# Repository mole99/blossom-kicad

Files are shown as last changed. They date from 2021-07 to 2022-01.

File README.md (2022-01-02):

# Blossom

Blossom is my attempt at an Open Source Board designed using [KiCad 6](https://www.kicad.org/) and [OpenSCAD](https://openscad.org/). It packs 12 LEDs driven by a technique called Charlieplexing and 3 Buttons which are read using one analog pin. The board itself resembles a flower, at its heart an ATtiny85 MCU.

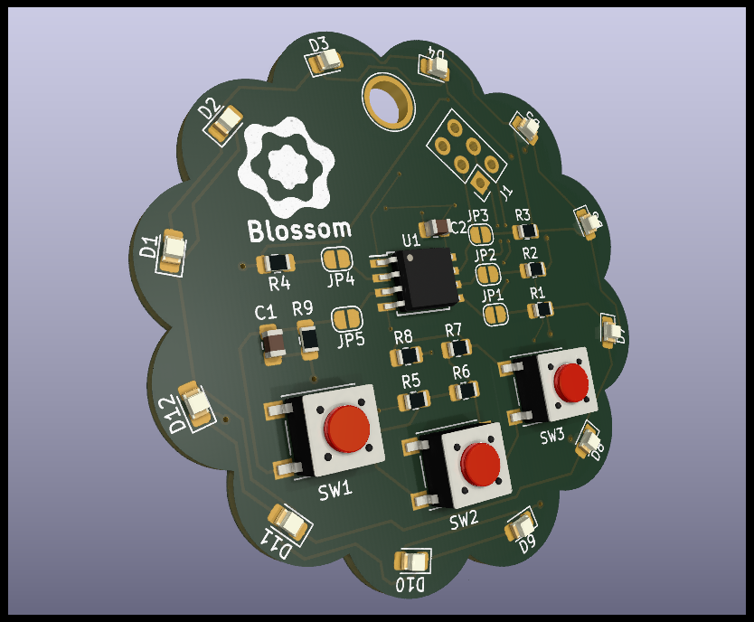
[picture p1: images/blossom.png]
3D-render


The firmware for the board can be found in the [blossom-firmware](https://github.com/mole99/blossom-firmware) repository.

Have a look at the interactive BOM [here](https://htmlpreview.github.io/?https://github.com/mole99/blossom-kicad/blob/main/ibom/ibom.html).

# The KiCad Project

The project related files are placed in `kicad/`. The aim of the project was to learn a lot and besides that create a small PCB controlled by an ATtiny85 which blinks some LEDs and reads in input from three buttons.

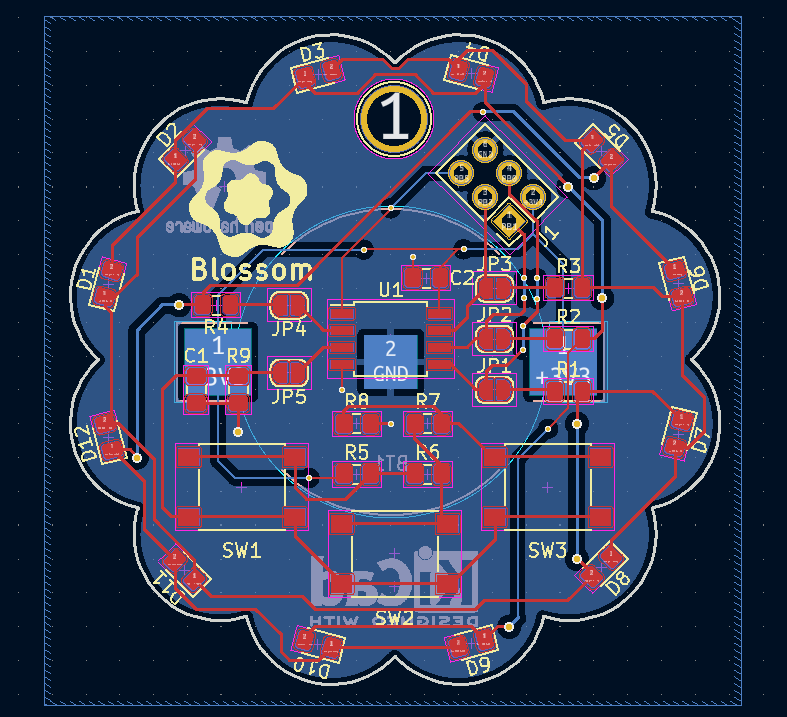
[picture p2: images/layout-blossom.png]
layout


The 12 LEDs are controlled by just 4 pins using [Charlieplexing](https://en.wikipedia.org/wiki/Charlieplexing). The current states of the 3 buttons is sampled by charging a capacitor depending on which button is pressed and reading the analog input.

# The board outline

You can find the files used to create the board outline and various positions for holes and the position of the LEDs under `cad/`.

To open the files you need to install [OpenSCAD](https://openscad.org/).

# Custom silkscreen icons

Using a tool called `svg2mod` I was able to convert a SVG icon drawn in Inkscape to a KiCad footprint module file. You can find the files in `icons/`.

You can easily do this with this command:

> svg2mod -i blossom.svg -o blossom.kicad_mod -p 0.1

where `p` stands for precision, the smaller the more precise.

# The finished PCB

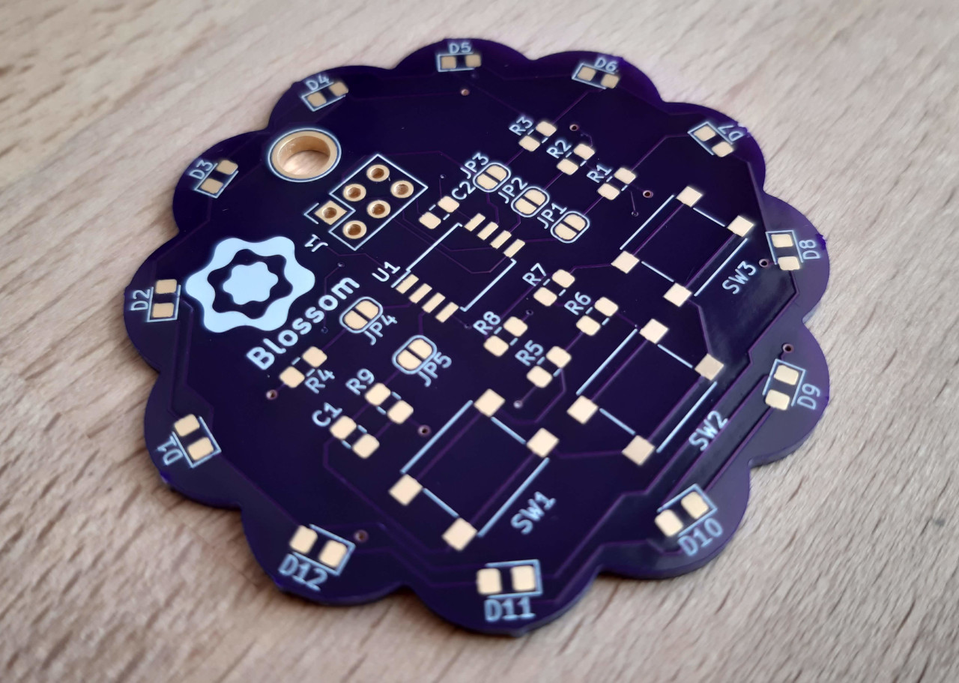
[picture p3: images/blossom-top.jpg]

(This is the 1.0 version)

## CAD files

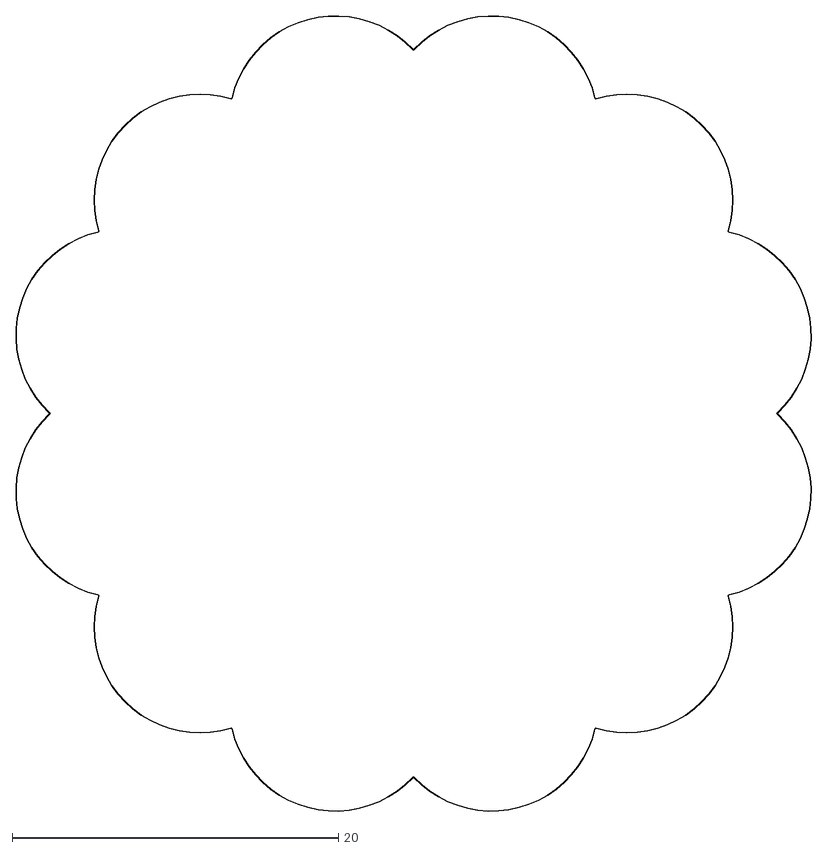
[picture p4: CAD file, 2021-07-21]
cad/blossom.dxf
48.7 x 48.7

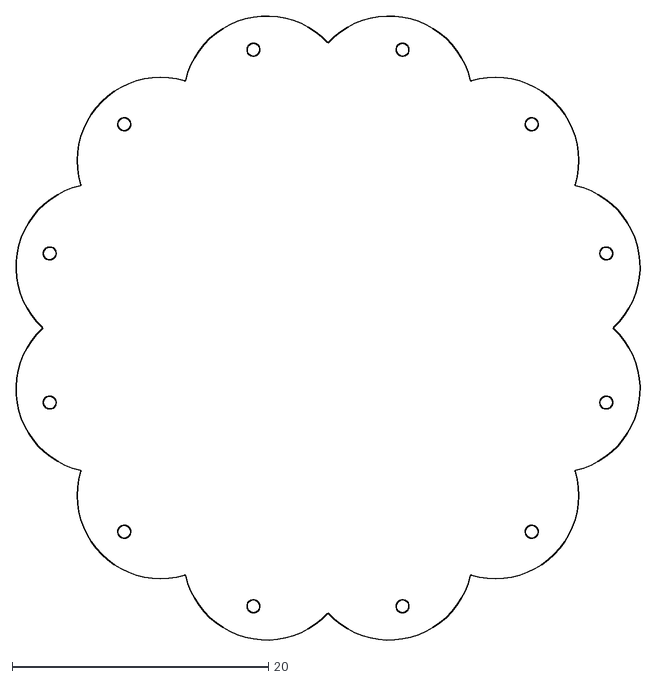
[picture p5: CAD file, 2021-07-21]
cad/led_positions.dxf
48.7 x 48.7

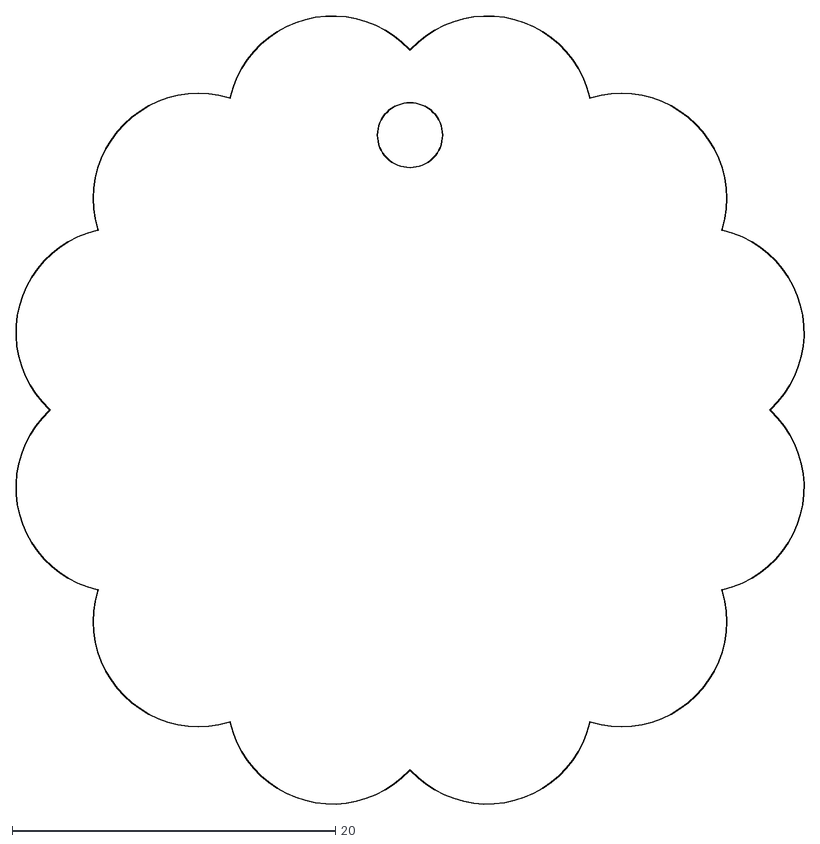
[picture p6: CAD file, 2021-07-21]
cad/drills.dxf
48.7 x 48.7

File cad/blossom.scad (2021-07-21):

$fn=64;

leafs = 12;
leafRadius = 6.5;

pcbRadius = 25; // mm
middleRadius = pcbRadius - leafRadius;
drillDistance = 17;

offsetAngle = 15;
r=0.6;g=0.0;b=0.4;a=0.8;


union()
{
    color([r,g,b,a]) circle(r=middleRadius);

    for ( i = [0 : leafs] )
    {
        rotate(a=[0,0,360/leafs*i + offsetAngle])
        {
          translate([0,middleRadius]) color([r,g,b,a]) circle(r=leafRadius);
        }
    }
}

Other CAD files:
cad/drills.scad
cad/led_positions.scad

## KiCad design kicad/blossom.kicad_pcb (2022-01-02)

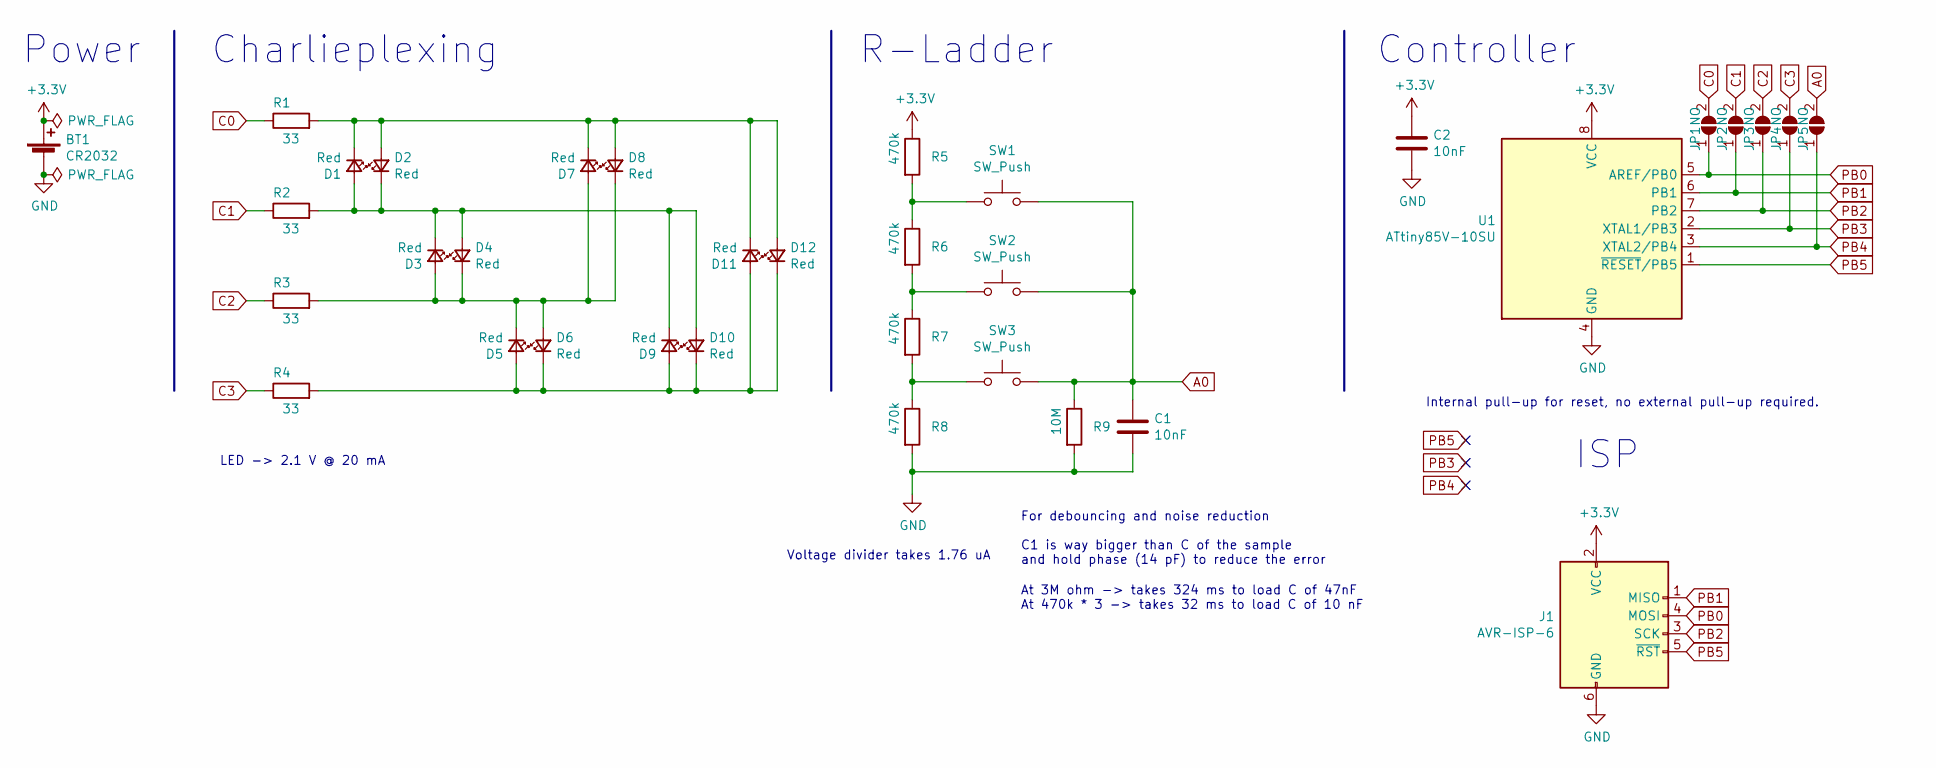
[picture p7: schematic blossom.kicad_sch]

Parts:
BT1: CR2032; BC2001
C1, C2: 10nF; C_0805_2012Metric_Pad1.15x1.40mm_HandSolder
D1, D2, D3, D4, D5, D6, D7, D8, D9, D10, D11, D12: Red; LED_0805_2012Metric_Pad1.15x1.40mm_HandSolder
J1: AVR-ISP-6; PinSocket_2x03_P2.54mm_Vertical
JP1, JP2, JP3, JP4, JP5: NO; SolderJumper-2_P1.3mm_Open_RoundedPad1.0x1.5mm
R1, R2, R3, R4: 33; R_0805_2012Metric_Pad1.15x1.40mm_HandSolder
R5, R6, R7, R8: 470k; R_0805_2012Metric_Pad1.15x1.40mm_HandSolder
R9: 10M; R_0805_2012Metric_Pad1.15x1.40mm_HandSolder
SW1, SW2, SW3: SW_Push; SW_Push_1P1T_NO_6x6mm_H9.5mm
U1: ATtiny85V-10SU; SOIC-8W_5.3x5.3mm_P1.27mm

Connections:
+3V3: BT1.1 (+), C2.1, J1.2 (VCC), R5.1, U1.8 (VCC)
A0: C1.1, JP5.2 (B), R9.1, SW1.2, SW2.2, SW3.2
C0: JP1.2 (B), R1.1
C1: JP2.2 (B), R2.1
C2: JP3.2 (B), R3.1
C3: JP4.2 (B), R4.1
GND: BT1.2 (-), C1.2, C2.2, J1.6 (GND), R8.2, R9.2, U1.4 (GND)
unnamed: D1.1 (K), D2.2 (A), D7.1 (K), D8.2 (A), D11.1 (K), D12.2 (A), R1.2
unnamed: D1.2 (A), D2.1 (K), D3.1 (K), D4.2 (A), D9.1 (K), D10.2 (A), R2.2
unnamed: D3.2 (A), D4.1 (K), D5.1 (K), D6.2 (A), D7.2 (A), D8.1 (K), R3.2
unnamed: D5.2 (A), D6.1 (K), D9.2 (A), D10.1 (K), D11.2 (A), D12.1 (K), R4.2
unnamed: R5.2, R6.1, SW1.1
unnamed: R6.2, R7.1, SW2.1
unnamed: R7.2, R8.1, SW3.1
PB0: J1.4 (MOSI), JP1.1 (A), U1.5 (AREF/PB0)
PB1: J1.1 (MISO), JP2.1 (A), U1.6 (PB1)
PB2: J1.3 (SCK), JP3.1 (A), U1.7 (PB2)
PB3: JP4.1 (A), U1.2 (XTAL1/PB3)
PB4: JP5.1 (A), U1.3 (XTAL2/PB4)
PB5: J1.5 (~RST), U1.1 (~RESET/PB5)

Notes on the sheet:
Power
Controller
At 3M ohm -> takes 324 ms to load C of 47nF At 470k * 3 -> takes 32 ms to load C of 10 nF
R-Ladder
Charlieplexing
Voltage divider takes 1.76 uA
ISP
Internal pull-up for reset, no external pull-up required.
LED -> 2.1 V @ 20 mA
For debouncing and noise reduction C1 is way bigger than C of the sample and hold phase (14 pF) to reduce the error

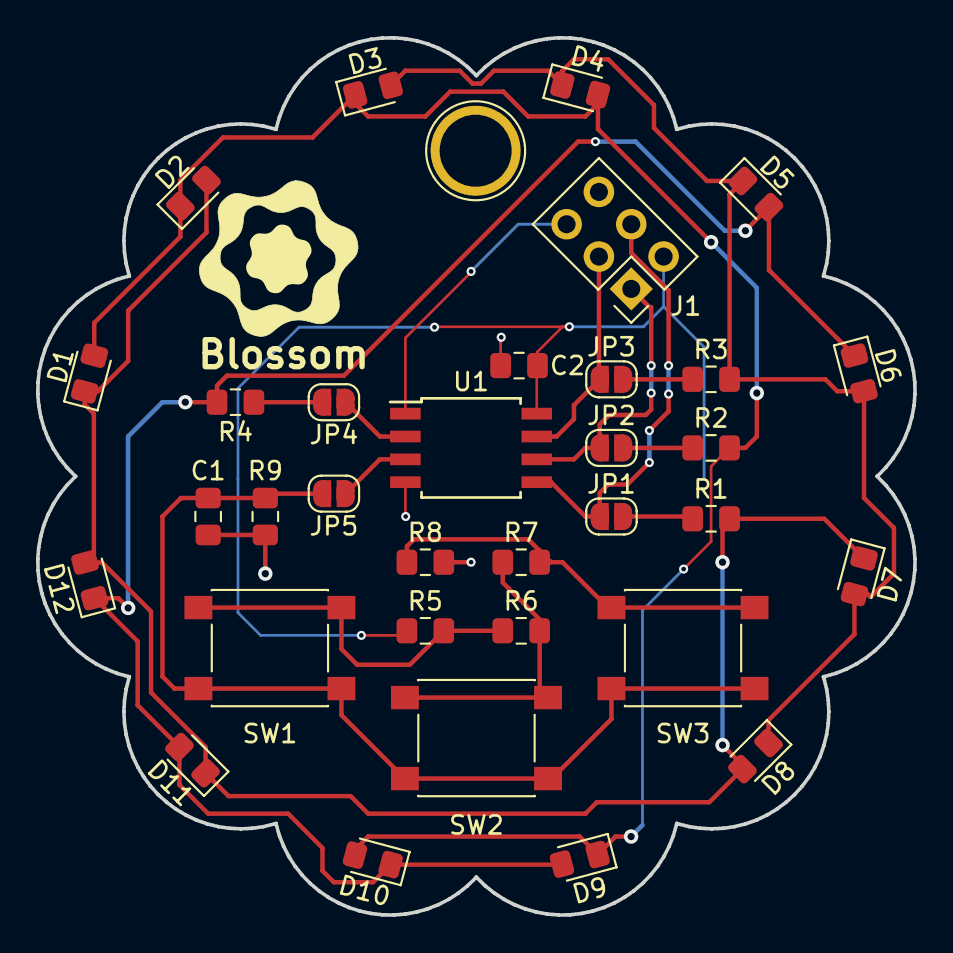
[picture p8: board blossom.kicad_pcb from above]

Board: 2 copper layers, 48.7 x 48.7 mm, 35 parts (1 on the bottom side), 20 nets.

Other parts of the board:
svg2mod: G***; blossom

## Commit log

2021-07-21 Add initial project files
    [blossom.dxf, blossom.kicad_pcb, blossom.scad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]
2022-01-02 Migrate to KiCad 6
    [blossom.kicad_pcb, blossom.kicad_sch, blossom.sch]
2022-01-02 Add IBOM
    [blossom.kicad_pcb]
